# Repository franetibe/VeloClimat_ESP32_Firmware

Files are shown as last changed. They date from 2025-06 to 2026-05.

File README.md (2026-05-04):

# VeloClimat_ESP32_Firmware

Build a Veloclimap from A to Z.

# Dependencies 

- ESP-IDF
<br></br>

# Step 1: Unbox the components

You should have four components:

- A SHT40 I2C sensor
- A ESP32 Board
- A SPST switch
- A 1800 mAh LiPo Battery 

The following hardware have been tested:

- ESP32-WROOM-32E
- ESP32-C3 (devkit-lipo)
- SHT40 (DFRobot module v1)

-> TODO add picture before welding

# Step 2: Weld the components

The components should be welded using the following pinout and diagram

## Pinout

ESP32 GPIO_NUM_8 -> SHT40 SDA  
ESP32 GPIO_NUM_9 -> SHT40 SCL  
ESP32 GND        -> SHT40 GND  
ESP32 3.3V       -> SHT40 VCC

ESP32 BAT-       -> Switch side 1  
Switch side 2    -> BAT-  
BAT+             -> ESP32 BAT+

## Diagram

```mermaid
flowchart LR
    subgraph ESP32 [ESP32 Board]
        P8(GPIO_NUM_8)
        P9(GPIO_NUM_9)
        GND(GND)
        V33(3.3V)
        EBAT_P(BAT+)
        EBAT_M(BAT-)
    end

    subgraph SHT40 [SHT40 DFRobot Module]
        SDA(SDA)
        SCL(SCL)
        SGND(GND)
        SVCC(VCC)
    end

    subgraph Power [1800mAh LiPo Battery]
        BP(BAT+)
        BM(BAT-)
    end

    subgraph Switch [SPST Switch]
        S1(Side 1)
        S2(Side 2)
    end

    %% I2C Connections
    P8 <-->|I2C Data| SDA
    P9 --->|I2C Clock| SCL
    GND --- SGND
    V33 ---> SVCC

    %% Power Connections
    BP ---> EBAT_P
    BM --- S2
    S1 --- EBAT_M
```
-> TODO add picture after welding

# Step 3: Install the app

Open a terminal

Clone the repository on your laptop
```bash
git clone https://github.com/franetibe/VeloClimat_ESP32_Firmware.git
```

Build the app on your laptop
```bash
get_idf # or make sure you have the idf environment loaded in your terminal
cd VeloClimat_ESP32_Firmware
idf.py build
```

-> Connect the ESP32 with the laptop ?

Flash the app on the ESP32
```bash
idf.py flash monitor
```

# Step 4: Test the communication between the app and the hardware

-> TODO Rewrite this part ?

- Set the target for your esp32 model (example `idf.py set_target esp32-c3`)
- Make sure you have the flash size of your particular esp32 set right (`idf.py menuconfig`)
- Make sure you have the I2C pins set right `GPIO_SDA_PIN` and  `GPIO_SCL_PIN` defines in the gatts_server.c
- You can choose the accuracy level you want by changing the line `uint8_t command[1] = {SHT40_MEDIUM_ACCURACY_MEASURMENT_COMMAND};` in `sht_get_data`

# Step 5: Mount the shield and place the hardware inside the shield

-> TODO Rewrite this part and add pictures ?

- You can soften the switch hole with a heat gun or a hot air station before inserting it
- The battery is taped to the back with a piece of nano tape
- The battery connector on the ESP32 can be desoldered to solder the wires through the vias
- The rest is soldered on headers and covered with heat shrink tube

# Additional information

- As it stands a 1800mAh battery should last about 26hrs

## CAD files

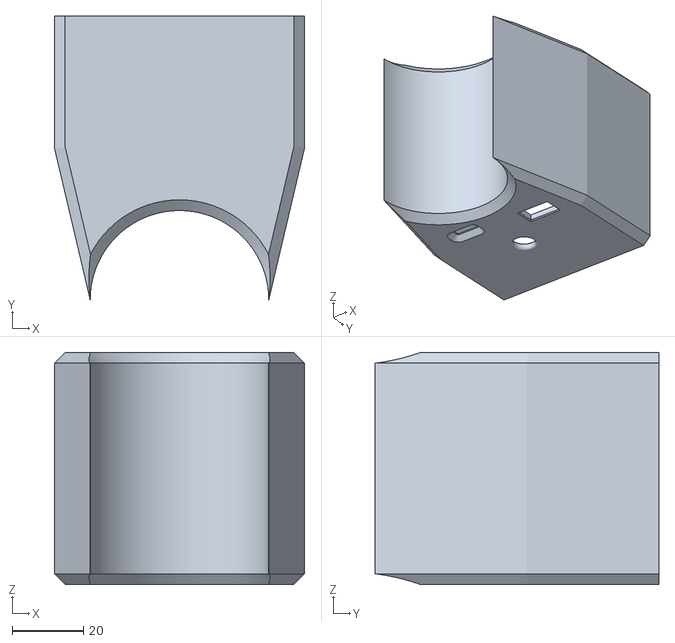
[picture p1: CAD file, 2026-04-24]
case/CaseVeloclimat.stl
70.0 x 79.4 x 65.0

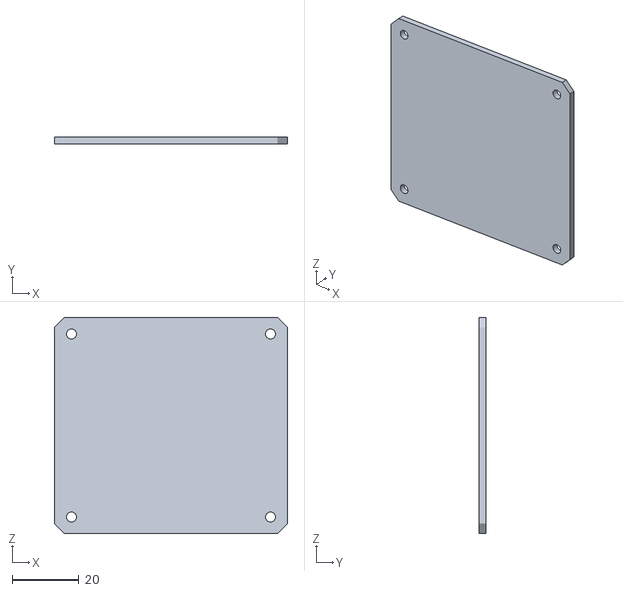
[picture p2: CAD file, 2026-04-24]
case/TopVeloclimat.stl
70.0 x 2.00 x 65.0

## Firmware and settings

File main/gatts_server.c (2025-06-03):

#include <stdio.h>
#include <stdlib.h>
#include <string.h>
#include <inttypes.h>
#include "freertos/FreeRTOS.h"
#include "freertos/task.h"
#include "freertos/event_groups.h"
#include "esp_system.h"
#include "esp_mac.h"
#include "esp_log.h"
#include "nvs_flash.h"
#include "esp_bt.h"

#include "esp_gap_ble_api.h"
#include "esp_gatts_api.h"
#include "esp_bt_defs.h"
#include "esp_bt_main.h"
#include "esp_bt_device.h"
#include "esp_gatt_common_api.h"

#include "driver/i2c_master.h"

#include "sdkconfig.h"

#define GATTS_TAG "VC_SENSOR"

///Declare the static function
static void gatts_profile_a_event_handler(esp_gatts_cb_event_t event, esp_gatt_if_t gatts_if, esp_ble_gatts_cb_param_t *param);

typedef struct {
    float temperature;
    float humidity;
} sensor_data;

typedef struct {
    i2c_master_bus_handle_t bus_handle;
    i2c_master_dev_handle_t dev_handle;
    sensor_data latest_data;
} sht_sensor;

#define GPIO_SDA_PIN    GPIO_NUM_8
#define GPIO_SCL_PIN    GPIO_NUM_9
#define I2C_TIMEOUT     150

#define GATTS_SERVICE_UUID   0x181A
#define GATTS_CHAR_UUID      0xFF01
#define GATTS_NUM_HANDLE     4

#define SENSOR_ADDRESS          0x44
#define SENSOR_BUS_COMM_SPEED   400000

#define SHT40_HIGH_ACCURACY_MEASURMENT_COMMAND      0xFD    //  ~0.04°C  6.9-8.2ms
#define SHT40_MEDIUM_ACCURACY_MEASURMENT_COMMAND    0xF6    //  ~0.07°C  3.7-4.5ms
#define SHT40_LOW_ACCURACY_MEASURMENT_COMMAND       0xE0    //  ~0.1°C   1.3-1.7ms


static char device_name[ESP_BLE_ADV_NAME_LEN_MAX] = "CHANGE_ME";


static sht_sensor sht40 = {
    .bus_handle = 0,
    .dev_handle = 0,
    .latest_data = {0},
};

static esp_gatt_char_prop_t sensor_char_properties = 0;

static const sensor_data default_sensor_data = {
    .humidity = 0.0f,
    .temperature = 0.0f,
};

static esp_attr_value_t gatts_char1_default =
{
    .attr_max_len = sizeof(sensor_data),
    .attr_len     = sizeof(sensor_data),
    .attr_value   = (uint8_t*)&default_sensor_data,
};

static uint8_t adv_config_done = 0;
#define adv_config_flag      (1 << 0)
#define scan_rsp_config_flag (1 << 1)


uint8_t sht_crc8(const uint8_t *data, int len) {
    uint8_t crc = 0xFF; // Initial value
    uint8_t polynomial = 0x31; // CRC-8 polynomial 

    for (int i = 0; i < len; i++) {
        crc ^= data[i];
        for (int j = 0; j < 8; j++) {
            if ((crc & 0x80) != 0) {
                crc = (uint8_t)((crc << 1) ^ polynomial);
            } else {
                crc <<= 1;
            }
        }
    }
    return crc;
}

void sht_configure() {
    const i2c_master_bus_config_t i2c_mst_config = {
        .clk_source = I2C_CLK_SRC_DEFAULT,
        .i2c_port = 0,
        .scl_io_num = GPIO_SCL_PIN,
        .sda_io_num = GPIO_SDA_PIN,
        .glitch_ignore_cnt = 7,
        .flags.enable_internal_pullup = true,
    };

    esp_err_t err = i2c_new_master_bus(&i2c_mst_config, &sht40.bus_handle);
    if(err != ESP_OK) {
        ESP_LOGE(GATTS_TAG, "Failed to create I2C master bus: %s", esp_err_to_name(err));
        return;
    }

    const i2c_device_config_t dev_cfg = {
        .dev_addr_length = I2C_ADDR_BIT_LEN_7,
        .device_address = SENSOR_ADDRESS,
        .scl_speed_hz = SENSOR_BUS_COMM_SPEED,
    };

    err = i2c_master_bus_add_device(sht40.bus_handle, &dev_cfg, &sht40.dev_handle);
    if(err != ESP_OK) {
        ESP_LOGE(GATTS_TAG, "Failed to add a device to I2C bus: %s", esp_err_to_name(err));
        return;
    }
}

void sht_get_data(sensor_data *meas) {

    uint8_t command[1] = {SHT40_MEDIUM_ACCURACY_MEASURMENT_COMMAND};
    uint8_t rcv_buff[6] = {0};

    esp_err_t err = i2c_master_transmit(sht40.dev_handle, command, sizeof(command), pdMS_TO_TICKS(I2C_TIMEOUT));
    if(err != ESP_OK) {
        ESP_LOGE(GATTS_TAG, "Failed to transmit to I2C bus: %s", esp_err_to_name(err));
        return;
    }

    // Wait 10ms for the sht40 to do its measurment
    esp_rom_delay_us(10*1000);


    err = i2c_master_receive(sht40.dev_handle, rcv_buff, sizeof(rcv_buff), pdMS_TO_TICKS(I2C_TIMEOUT));
    if(err != ESP_OK) {
        ESP_LOGE(GATTS_TAG, "Failed to receive from I2C bus: %s", esp_err_to_name(err));
        return;
    }

    
    // Check CRC for temperature data
    if (sht_crc8(rcv_buff, 2) != rcv_buff[2]) {
        ESP_LOGW(GATTS_TAG, "Temperature data CRC mismatch!");
    }

    // Check CRC for humidity data
    if (sht_crc8(rcv_buff + 3, 2) != rcv_buff[5]) {
        ESP_LOGW(GATTS_TAG, "Humidity data CRC mismatch!");
    }
    
    // Byte swap 
    uint16_t raw_temp = (rcv_buff[0] << 8) | rcv_buff[1];
    uint16_t raw_humi = (rcv_buff[3] << 8) | rcv_buff[4];

    // Conversion from ticks to value from the datasheet
    meas->temperature = -45 + 175.0f * raw_temp / 65535;
    meas->humidity = -6 + 125.0f * raw_humi / 65535;

    // Humidity can exceed the normal values so we clamp them (said in the datasheet)
    if(meas->humidity > 100) meas->humidity = 100;
    else if (meas->humidity < 0) meas->humidity = 0;
}

void sht_destroy() {
    esp_err_t err = i2c_master_bus_rm_device(sht40.dev_handle);
    if(err != ESP_OK) {
        ESP_LOGE(GATTS_TAG, "Failed to remove a device from I2C bus: %s", esp_err_to_name(err));
    }

    err = i2c_del_master_bus(sht40.bus_handle);
    if(err != ESP_OK) {
        ESP_LOGE(GATTS_TAG, "Failed to delete I2C master bus: %s", esp_err_to_name(err));
    }
}

static uint8_t adv_service_uuid128[32] = {
    /* LSB <--------------------------------------------------------------------------------> MSB */
    //first uuid, 16bit, [12],[13] is the value
    0xfb, 0x34, 0x9b, 0x5f, 0x80, 0x00, 0x00, 0x80, 0x00, 0x10, 0x00, 0x00, 0xEE, 0x00, 0x00, 0x00,
    //second uuid, 32bit, [12], [13], [14], [15] is the value
    0xfb, 0x34, 0x9b, 0x5f, 0x80, 0x00, 0x00, 0x80, 0x00, 0x10, 0x00, 0x00, 0xFF, 0x00, 0x00, 0x00,
};

// The length of adv data must be less than 31 bytes
//adv data
static esp_ble_adv_data_t adv_data = {
    .set_scan_rsp = false,
    .include_name = true,
    .include_txpower = false,
    .min_interval = 0x0006, //slave connection min interval, Time = min_interval * 1.25 msec
    .max_interval = 0x0010, //slave connection max interval, Time = max_interval * 1.25 msec
    .appearance = 0x00,
    .manufacturer_len = 0,
    .p_manufacturer_data =  NULL,
    .service_data_len = 0,
    .p_service_data = NULL,
    .service_uuid_len = sizeof(adv_service_uuid128),
    .p_service_uuid = adv_service_uuid128,
    .flag = (ESP_BLE_ADV_FLAG_GEN_DISC | ESP_BLE_ADV_FLAG_BREDR_NOT_SPT),
};
// scan response data
static esp_ble_adv_data_t scan_rsp_data = {
    .set_scan_rsp = true,
    .include_name = true,
    .include_txpower = true,
    .appearance = 0x00,
    .manufacturer_len = 0,
    .p_manufacturer_data =  NULL,
    .service_data_len = 0,
    .p_service_data = NULL,
    .service_uuid_len = sizeof(adv_service_uuid128),
    .p_service_uuid = adv_service_uuid128,
    .flag = (ESP_BLE_ADV_FLAG_GEN_DISC | ESP_BLE_ADV_FLAG_BREDR_NOT_SPT),
};

static esp_ble_adv_params_t adv_params = {
    .adv_int_min        = 0x40,
    .adv_int_max        = 0x80,
    .adv_type           = ADV_TYPE_IND,
    .own_addr_type      = BLE_ADDR_TYPE_PUBLIC,
    .channel_map        = ADV_CHNL_ALL,
    .adv_filter_policy = ADV_FILTER_ALLOW_SCAN_ANY_CON_ANY,
};

#define PROFILE_NUM 1
#define PROFILE_A_APP_ID 0

struct gatts_profile_inst {
    esp_gatts_cb_t gatts_cb;
    uint16_t gatts_if;
    uint16_t app_id;
    uint16_t conn_id;
    uint16_t service_handle;
    esp_gatt_srvc_id_t service_id;
    uint16_t char_handle;
    esp_bt_uuid_t char_uuid;
    esp_gatt_perm_t perm;
    esp_gatt_char_prop_t property;
    uint16_t descr_handle;
    esp_bt_uuid_t descr_uuid;
};

/* One gatt-based profile one app_id and one gatts_if, this array will store the gatts_if returned by ESP_GATTS_REG_EVT */
static struct gatts_profile_inst gl_profile_tab[PROFILE_NUM] = {
    [PROFILE_A_APP_ID] = {
        .gatts_cb = gatts_profile_a_event_handler,
        .gatts_if = ESP_GATT_IF_NONE,       /* Not get the gatt_if, so initial is ESP_GATT_IF_NONE */
    },
};



static void gap_event_handler(esp_gap_ble_cb_event_t event, esp_ble_gap_cb_param_t *param)
{
    switch (event) {

    case ESP_GAP_BLE_ADV_DATA_SET_COMPLETE_EVT:
        adv_config_done &= (~adv_config_flag);
        if (adv_config_done == 0){
            esp_ble_gap_start_advertising(&adv_params);
        }
        break;
    case ESP_GAP_BLE_SCAN_RSP_DATA_SET_COMPLETE_EVT:
        adv_config_done &= (~scan_rsp_config_flag);
        if (adv_config_done == 0){
            esp_ble_gap_start_advertising(&adv_params);
        }
        break;
    case ESP_GAP_BLE_ADV_START_COMPLETE_EVT:
        //advertising start complete event to indicate advertising start successfully or failed
        if (param->adv_start_cmpl.status != ESP_BT_STATUS_SUCCESS) {
            ESP_LOGE(GATTS_TAG, "Advertising start failed, status %d", param->adv_start_cmpl.status);
            break;
        }
        ESP_LOGI(GATTS_TAG, "Advertising start successfully");
        break;
    case ESP_GAP_BLE_ADV_STOP_COMPLETE_EVT:
        if (param->adv_start_cmpl.status != ESP_BT_STATUS_SUCCESS) {
            ESP_LOGE(GATTS_TAG, "Advertising stop failed, status %d", param->adv_stop_cmpl.status);
            break;
        }
        ESP_LOGI(GATTS_TAG, "Advertising stop successfully");
        break;
    case ESP_GAP_BLE_UPDATE_CONN_PARAMS_EVT:
         ESP_LOGI(GATTS_TAG, "Connection params update, status %d, conn_int %d, latency %d, timeout %d",
                  param->update_conn_params.status,
                  param->update_conn_params.conn_int,
                  param->update_conn_params.latency,
                  param->update_conn_params.timeout);
        break;
    case ESP_GAP_BLE_SET_PKT_LENGTH_COMPLETE_EVT:
        ESP_LOGI(GATTS_TAG, "Packet length update, status %d, rx %d, tx %d",
                  param->pkt_data_length_cmpl.status,
                  param->pkt_data_length_cmpl.params.rx_len,
                  param->pkt_data_length_cmpl.params.tx_len);
        break;
    default:
        break;
    }
}


static void gatts_profile_a_event_handler(esp_gatts_cb_event_t event, esp_gatt_if_t gatts_if, esp_ble_gatts_cb_param_t *param) {
    switch (event) {
    case ESP_GATTS_REG_EVT:
        ESP_LOGI(GATTS_TAG, "GATT server register, status %d, app_id %d, gatts_if %d", param->reg.status, param->reg.app_id, gatts_if);
        gl_profile_tab[PROFILE_A_APP_ID].service_id.is_primary = true;
        gl_profile_tab[PROFILE_A_APP_ID].service_id.id.inst_id = 0x00;
        gl_profile_tab[PROFILE_A_APP_ID].service_id.id.uuid.len = ESP_UUID_LEN_16;
        gl_profile_tab[PROFILE_A_APP_ID].service_id.id.uuid.uuid.uuid16 = GATTS_SERVICE_UUID;

        esp_err_t set_dev_name_ret = esp_ble_gap_set_device_name(device_name);
        if (set_dev_name_ret){
            ESP_LOGE(GATTS_TAG, "set device name failed, error code = %x", set_dev_name_ret);
        }

        //config adv data
        esp_err_t ret = esp_ble_gap_config_adv_data(&adv_data);
        if (ret){
            ESP_LOGE(GATTS_TAG, "config adv data failed, error code = %x", ret);
        }
        adv_config_done |= adv_config_flag;
        //config scan response data
        ret = esp_ble_gap_config_adv_data(&scan_rsp_data);
        if (ret){
            ESP_LOGE(GATTS_TAG, "config scan response data failed, error code = %x", ret);
        }
        adv_config_done |= scan_rsp_config_flag;

        esp_ble_gatts_create_service(gatts_if, &gl_profile_tab[PROFILE_A_APP_ID].service_id, GATTS_NUM_HANDLE);
        break;
    case ESP_GATTS_READ_EVT: {
        ESP_LOGI(GATTS_TAG, "Characteristic read, conn_id %d, trans_id %" PRIu32 ", handle %d", param->read.conn_id, param->read.trans_id, param->read.handle);
        esp_gatt_rsp_t rsp;
        memset(&rsp, 0, sizeof(esp_gatt_rsp_t));
        sensor_data sdata;
        sht_get_data(&sdata);
        rsp.attr_value.handle = param->read.handle;
        rsp.attr_value.len = sizeof(sensor_data);
        memcpy(rsp.attr_value.value, &sdata, rsp.attr_value.len);
        esp_ble_gatts_send_response(gatts_if, param->read.conn_id, param->read.trans_id,
                                    ESP_GATT_OK, &rsp);
        break;
    }
    case ESP_GATTS_MTU_EVT:
        ESP_LOGI(GATTS_TAG, "MTU exchange, MTU %d", param->mtu.mtu);
        break;
    case ESP_GATTS_UNREG_EVT:
        break;
    case ESP_GATTS_CREATE_EVT:
        ESP_LOGI(GATTS_TAG, "Service create, status %d, service_handle %d", param->create.status, param->create.service_handle);
        gl_profile_tab[PROFILE_A_APP_ID].service_handle = param->create.service_handle;
        gl_profile_tab[PROFILE_A_APP_ID].char_uuid.len = ESP_UUID_LEN_16;
        gl_profile_tab[PROFILE_A_APP_ID].char_uuid.uuid.uuid16 = GATTS_CHAR_UUID;

        esp_ble_gatts_start_service(gl_profile_tab[PROFILE_A_APP_ID].service_handle);
        sensor_char_properties = ESP_GATT_CHAR_PROP_BIT_READ;
        esp_err_t add_char_ret = esp_ble_gatts_add_char(gl_profile_tab[PROFILE_A_APP_ID].service_handle, &gl_profile_tab[PROFILE_A_APP_ID].char_uuid,
                                                        ESP_GATT_PERM_READ,
                                                        sensor_char_properties,
                                                        &gatts_char1_default, NULL);
        if (add_char_ret){
            ESP_LOGE(GATTS_TAG, "add char failed, error code =%x",add_char_ret);
        }
        break;
    case ESP_GATTS_ADD_INCL_SRVC_EVT:
        break;
    case ESP_GATTS_ADD_CHAR_EVT: {
        uint16_t length = 0;
        const uint8_t *prf_char;

        ESP_LOGI(GATTS_TAG, "Characteristic add, status %d, attr_handle %d, service_handle %d",
                param->add_char.status, param->add_char.attr_handle, param->add_char.service_handle);
        gl_profile_tab[PROFILE_A_APP_ID].char_handle = param->add_char.attr_handle;
        gl_profile_tab[PROFILE_A_APP_ID].descr_uuid.len = ESP_UUID_LEN_16;
        gl_profile_tab[PROFILE_A_APP_ID].descr_uuid.uuid.uuid16 = ESP_GATT_UUID_CHAR_CLIENT_CONFIG;
        esp_err_t get_attr_ret = esp_ble_gatts_get_attr_value(param->add_char.attr_handle,  &length, &prf_char);
        if (get_attr_ret == ESP_FAIL){
            ESP_LOGE(GATTS_TAG, "ILLEGAL HANDLE");
        }

        ESP_LOGI(GATTS_TAG, "the gatts demo char length = %x", length);
        for(int i = 0; i < length; i++){
            ESP_LOGI(GATTS_TAG, "prf_char[%x] =%x",i,prf_char[i]);
        }
        esp_err_t add_descr_ret = esp_ble_gatts_add_char_descr(gl_profile_tab[PROFILE_A_APP_ID].service_handle, &gl_profile_tab[PROFILE_A_APP_ID].descr_uuid,
                                                                ESP_GATT_PERM_READ, NULL, NULL);
        if (add_descr_ret){
            ESP_LOGE(GATTS_TAG, "add char descr failed, error code =%x", add_descr_ret);
        }
        break;
    }
    case ESP_GATTS_ADD_CHAR_DESCR_EVT:
        gl_profile_tab[PROFILE_A_APP_ID].descr_handle = param->add_char_descr.attr_handle;
        ESP_LOGI(GATTS_TAG, "Descriptor add, status %d, attr_handle %d, service_handle %d",
                 param->add_char_descr.status, param->add_char_descr.attr_handle, param->add_char_descr.service_handle);
        break;
    case ESP_GATTS_START_EVT:
        ESP_LOGI(GATTS_TAG, "Service start, status %d, service_handle %d",
                 param->start.status, param->start.service_handle);
        break;
    case ESP_GATTS_STOP_EVT:
        break;
    case ESP_GATTS_CONNECT_EVT: {
        esp_ble_conn_update_params_t conn_params = {0};
        memcpy(conn_params.bda, param->connect.remote_bda, sizeof(esp_bd_addr_t));
        conn_params.latency = 0;
        conn_params.max_int = 0xA0;    // max_int = 0xA0*1.25ms = 200ms
        conn_params.min_int = 0x80;    // min_int = 0x80*1.25ms = 160ms
        conn_params.timeout = 200;    // timeout = 200*10ms = 2000ms
        ESP_LOGI(GATTS_TAG, "Connected, conn_id %u, remote "ESP_BD_ADDR_STR"", param->connect.conn_id, ESP_BD_ADDR_HEX(param->connect.remote_bda));
        gl_profile_tab[PROFILE_A_APP_ID].conn_id = param->connect.conn_id;
        //start sent the update connection parameters to the peer device.
        esp_ble_gap_update_conn_params(&conn_params);
        break;
    }
    case ESP_GATTS_DISCONNECT_EVT:
        ESP_LOGI(GATTS_TAG, "Disconnected, remote "ESP_BD_ADDR_STR", reason 0x%02x",
                 ESP_BD_ADDR_HEX(param->disconnect.remote_bda), param->disconnect.reason);
        esp_ble_gap_start_advertising(&adv_params);
        break;
    case ESP_GATTS_CONF_EVT:
        ESP_LOGI(GATTS_TAG, "Confirm receive, status %d, attr_handle %d", param->conf.status, param->conf.handle);
        if (param->conf.status != ESP_GATT_OK){
            ESP_LOG_BUFFER_HEX(GATTS_TAG, param->conf.value, param->conf.len);
        }
        break;
    case ESP_GATTS_EXEC_WRITE_EVT:
    case ESP_GATTS_DELETE_EVT:
    case ESP_GATTS_WRITE_EVT:
    case ESP_GATTS_OPEN_EVT:
    case ESP_GATTS_CANCEL_OPEN_EVT:
    case ESP_GATTS_CLOSE_EVT:
    case ESP_GATTS_LISTEN_EVT:
    case ESP_GATTS_CONGEST_EVT:
    default:
        break;
    }
}

static void gatts_event_handler(esp_gatts_cb_event_t event, esp_gatt_if_t gatts_if, esp_ble_gatts_cb_param_t *param)
{
    /* If event is register event, store the gatts_if for each profile */
    if (event == ESP_GATTS_REG_EVT) {
        if (param->reg.status == ESP_GATT_OK) {
            gl_profile_tab[param->reg.app_id].gatts_if = gatts_if;
        } else {
            ESP_LOGI(GATTS_TAG, "Reg app failed, app_id %04x, status %d",
                    param->reg.app_id,
                    param->reg.status);
            return;
        }
    }

    gl_profile_tab[PROFILE_A_APP_ID].gatts_cb(event, gatts_if, param);
}

void app_main(void)
{
    esp_err_t ret;

    // Initialize NVS.
    ret = nvs_flash_init();
    if (ret == ESP_ERR_NVS_NO_FREE_PAGES || ret == ESP_ERR_NVS_NEW_VERSION_FOUND) {
        ESP_ERROR_CHECK(nvs_flash_erase());
        ret = nvs_flash_init();
    }
    ESP_ERROR_CHECK( ret );

    // Gets mac address and uses the 3 last bytes to get a sort of unique identifier
    unsigned char mac_base[6] = {0};
    esp_efuse_mac_get_default(mac_base);
    snprintf(device_name, ESP_BLE_ADV_NAME_LEN_MAX, "VC_SENS_%X%X%X", mac_base[3], mac_base[4], mac_base[5]);

    sht_configure();

//////////////// Sensor test code ////////////////////


    // double tcount = 0.0f;
    // sensor_data sd = {0};
    // while (1)
    // {
    //     sht_get_data(&sd);
    //     printf("time: %fs\ntemp: %.2f°C\nHum: %.2f%%\n\n", tcount, sd.temperature, sd.humidity);
    //     vTaskDelay(1500/portTICK_PERIOD_MS);
    //     tcount += 1.5;
    // }

//////////////////////////////////////////////////////
    


    ESP_ERROR_CHECK(esp_bt_controller_mem_release(ESP_BT_MODE_CLASSIC_BT));

    esp_bt_controller_config_t bt_cfg = BT_CONTROLLER_INIT_CONFIG_DEFAULT();
    ret = esp_bt_controller_init(&bt_cfg);
    if (ret) {
        ESP_LOGE(GATTS_TAG, "%s initialize controller failed: %s", __func__, esp_err_to_name(ret));
        return;
    }

    ret = esp_bt_controller_enable(ESP_BT_MODE_BLE);
    if (ret) {
        ESP_LOGE(GATTS_TAG, "%s enable controller failed: %s", __func__, esp_err_to_name(ret));
        return;
    }

    ret = esp_bluedroid_init();
    if (ret) {
        ESP_LOGE(GATTS_TAG, "%s init bluetooth failed: %s", __func__, esp_err_to_name(ret));
        return;
    }
    ret = esp_bluedroid_enable();
    if (ret) {
        ESP_LOGE(GATTS_TAG, "%s enable bluetooth failed: %s", __func__, esp_err_to_name(ret));
        return;
    }
    // Note: Avoid performing time-consuming operations within callback functions.
    ret = esp_ble_gatts_register_callback(gatts_event_handler);
    if (ret){
        ESP_LOGE(GATTS_TAG, "gatts register error, error code = %x", ret);
        return;
    }
    ret = esp_ble_gap_register_callback(gap_event_handler);
    if (ret){
        ESP_LOGE(GATTS_TAG, "gap register error, error code = %x", ret);
        return;
    }
    ret = esp_ble_gatts_app_register(PROFILE_A_APP_ID);
    if (ret){
        ESP_LOGE(GATTS_TAG, "gatts app register error, error code = %x", ret);
        return;
    }
    esp_err_t local_mtu_ret = esp_ble_gatt_set_local_mtu(500);
    if (local_mtu_ret){
        ESP_LOGE(GATTS_TAG, "set local  MTU failed, error code = %x", local_mtu_ret);
    }

    return;
}

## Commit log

2025-05-27 sensor test
2026-04-24 readme pinout n tips
    [CaseVeloclimat.stl, TopVeloclimat.stl]
